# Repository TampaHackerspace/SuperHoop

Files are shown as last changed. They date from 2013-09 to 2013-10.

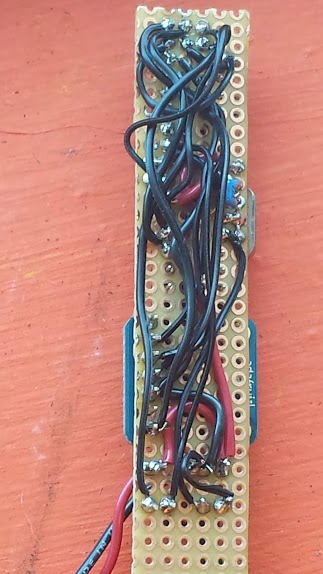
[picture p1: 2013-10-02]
code/SuperHoop_PCB/20131002_133408.jpg

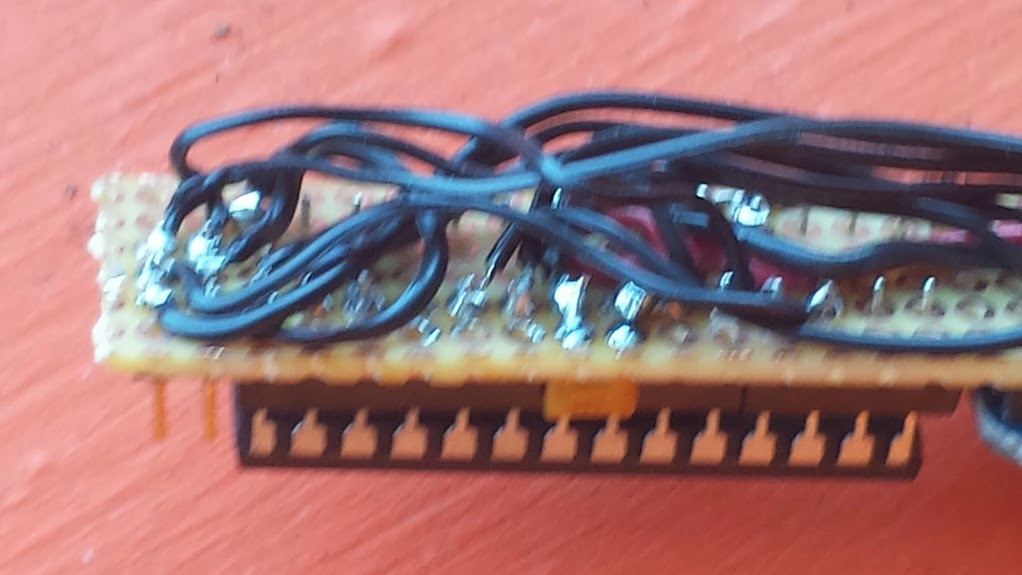
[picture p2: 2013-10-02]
code/SuperHoop_PCB/20131002_133213.jpg

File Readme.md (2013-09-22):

#Orlando Mini Maker Faire Project Planner
#Super Hoop

##Objective
Create a spectacle to attract attention and bring people into our exhibit so that our members can talk about their projects and we can promote our new Tampa Hackerspace. The project should be portable and kid friendly for future use.

##Project Idea
Embed addressable LEDs into clear hula hoops and instrument them with a programmable microcontroller and sensors so that we can make games and use them creatively.

##Sensors
accelerometer
photo electric cell and/or color sensor
grip sensor
proximity sensors

##Applications / Games
Persistence of Vision display. Spin the hoops rapidly to make colorful displays

How high can you go? Compete to see who can toss the hoop the highest and safely catch it.

Ring toss. Two or more players toss the hoops between themselves. Take a step back at each successful catch and keep going to see how long you can keep the game going.

Ultimate Ring Golf: Play it like ultimate frisbee but use the rings.

Horseshoes: Rings instead of horseshoes. Same rules.

Fasted hoop: First one to spin their hoop hula style 100 rotations wins.

Billboard: Use a wireless controller to stream dynamic text that displays while spinning?

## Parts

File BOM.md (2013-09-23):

- Atmega168 DIP IC
- 28 pin DIP IC socket
- Perfboard (4x6 phenolic or similar)
- Neopixel Addressable LEDs
- 3/4" Sharkbite Tubing (10ft stick per large hoop, 39 inch per small hoop)
- 1" Sharkbite tubing (holds batteries and Accelerometer)
- ADXL335 Accelerometer
- 16 MHz Crystal(1 per hoop)
- 22pF caps(2 per hoop)
- 10uF caps(2 per hoop)

##To buy:
- voltage boost circuit(3.7->5v)  NEED to order [one possible source: https://www.sparkfun.com/products/8290  ]
    we may be able to disable brown out fuse and run at 3.6v, but untested yet. need atmel programmer, Dan can't find his.
- Single AA battery holster (3 per large hoop, 2 per small hoop)  NEED to order [possible source: http://www.radioshack.com/product/index.jsp?productId=2062247  ]
- AA battery (3 per large hoop, 2 per small, Lithium 3.7v 2500ma or similar model 18650 with charger)  NEED to order
- VALCO Snap button (2 per hoop)  [mcmaster.com p/n 94282A250  http://www.mcmaster.com/#94282a250/=omgo4b   ]

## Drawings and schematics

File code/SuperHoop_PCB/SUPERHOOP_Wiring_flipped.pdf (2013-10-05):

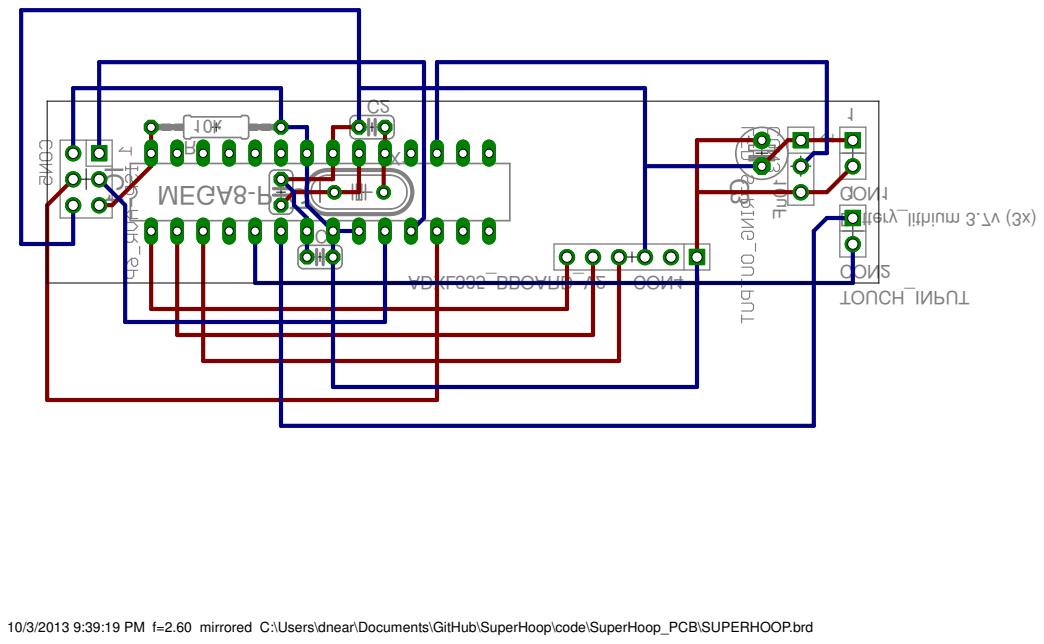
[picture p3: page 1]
MEGA8-P; Battery_lithium 3.7v (3x); ADXL335_BBOARD_V2; TOUCH_INPUT; C1CON1; CON4; CON2

10/3/2013 9:39:19 PM f=2.60 mirrored C:\Users\dnear\Documents\GitHub\SuperHoop\code\SuperHoop_PCB\SUPERHOOP.brd

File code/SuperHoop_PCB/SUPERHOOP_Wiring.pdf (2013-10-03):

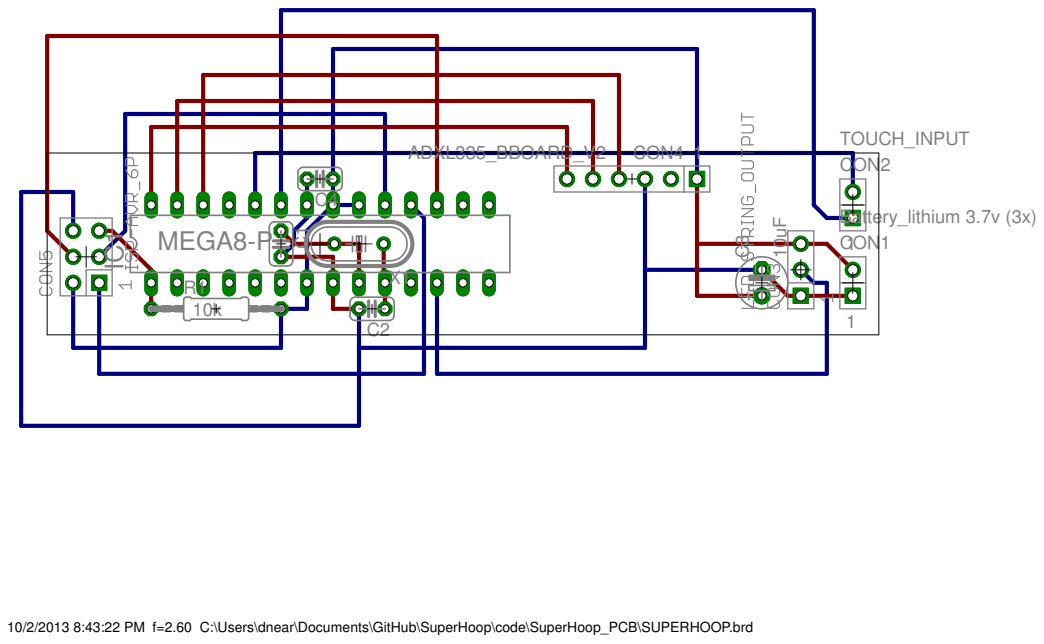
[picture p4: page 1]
C1 CON1; CON4; CON2; MEGA8-P; Battery_lithium 3.7v (3x); ADXL335_BBOARD_V2; TOUCH_INPUT

10/2/2013 8:43:22 PM f=2.60 C:\Users\dnear\Documents\GitHub\SuperHoop\code\SuperHoop_PCB\SUPERHOOP.brd

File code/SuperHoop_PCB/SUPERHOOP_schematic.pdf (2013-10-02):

A

A

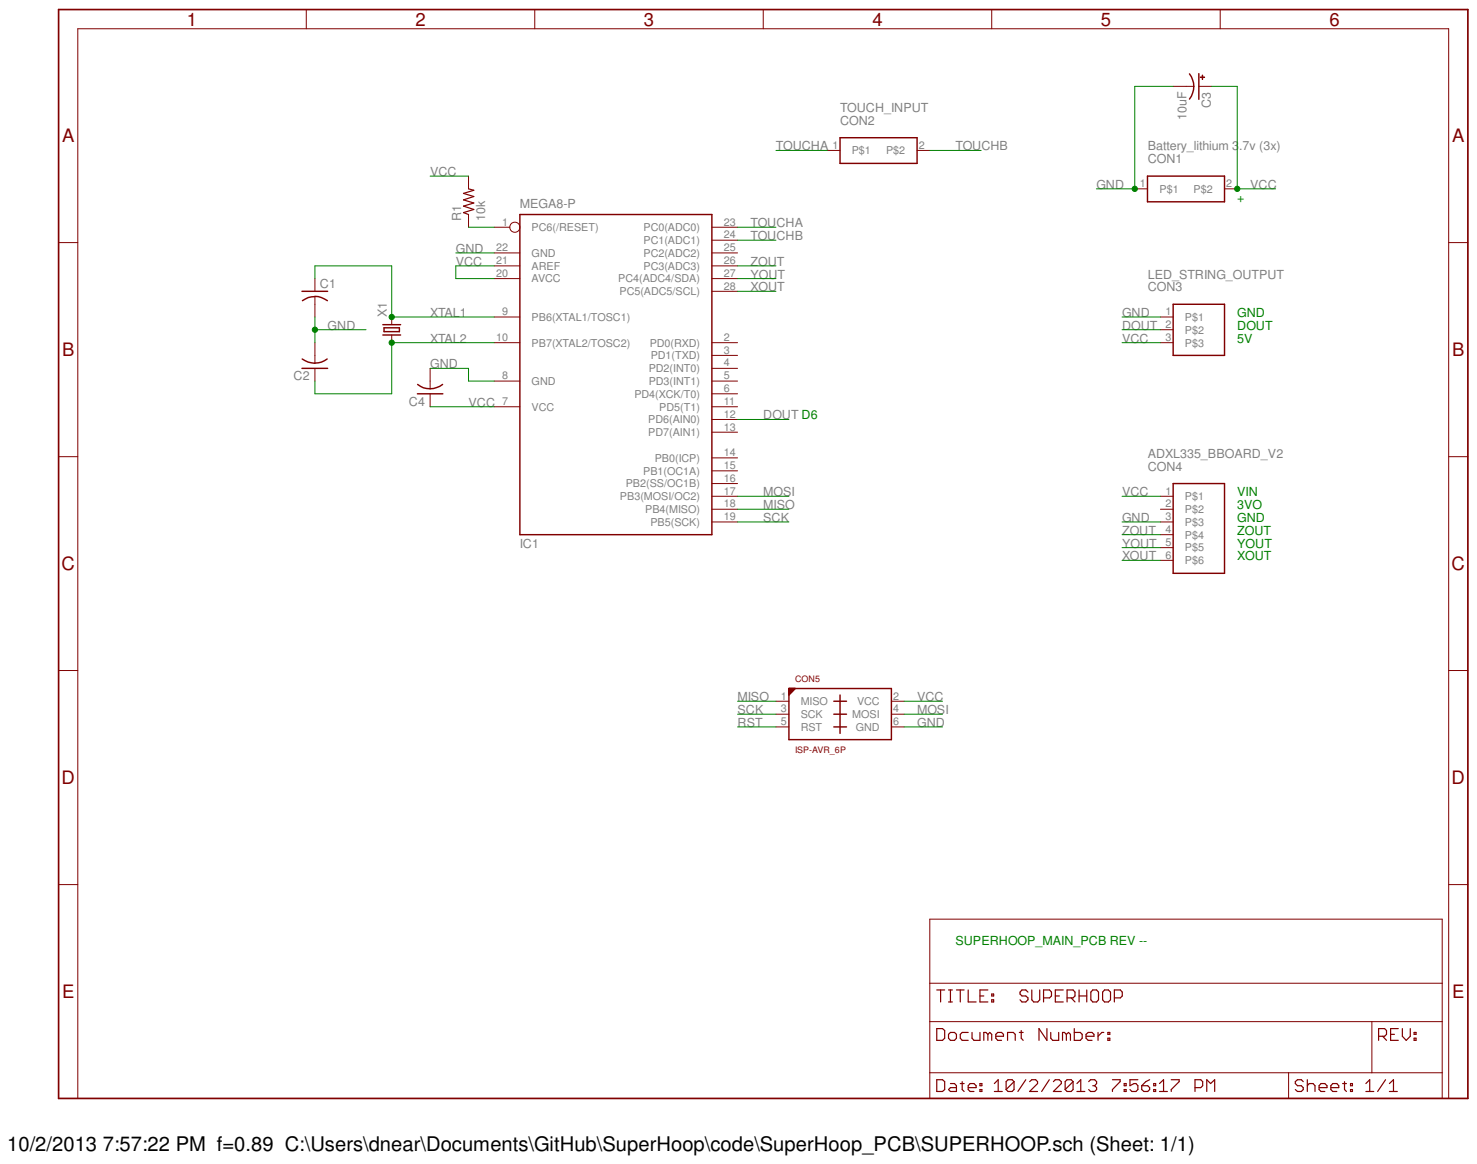
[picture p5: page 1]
Battery_lithium 3.7v (3x); LED_STRING_OUTPUT; ADXL335_BBOARD_V2; TOUCH_INPUT; PB5(SCK); PB7(XTAL2/TOSC2) 10; PB6(XTAL1/TOSC1) 9; GND 8; VCC 7; GND 22 AREF 21 AVCC 20; PB4(MISO); 18 PB3(MOSI/OC2); 15 PB0(ICP); PD7(AIN1); 13 PD6(AIN0); 11 PD4(XCK/T0); 6 PD3(INT1); 5 PD2(INT0); 4 PD1(TXD); 3 PD0(RXD); PC5(ADC5/SCL); 28 PC4(ADC4/SDA); 27 PC3(ADC3); 26 PC2(ADC2); 25 PC1(ADC1); 24 PC0(ADC0); 23 PC6(/RESET) 1; CON1; CON3; CON4; CON2; MISO 1 SCK 3; RST 5; GND; 6 MOSI; 4 VCC; VCC; DOUT; XTAL1; XTAL2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

MEGA8-P

10/2/2013 7:57:22 PM f=0.89 C:\Users\dnear\Documents\GitHub\SuperHoop\code\SuperHoop_PCB\SUPERHOOP.sch (Sheet: 1/1)

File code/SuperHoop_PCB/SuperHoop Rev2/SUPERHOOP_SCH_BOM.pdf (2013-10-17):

A

A

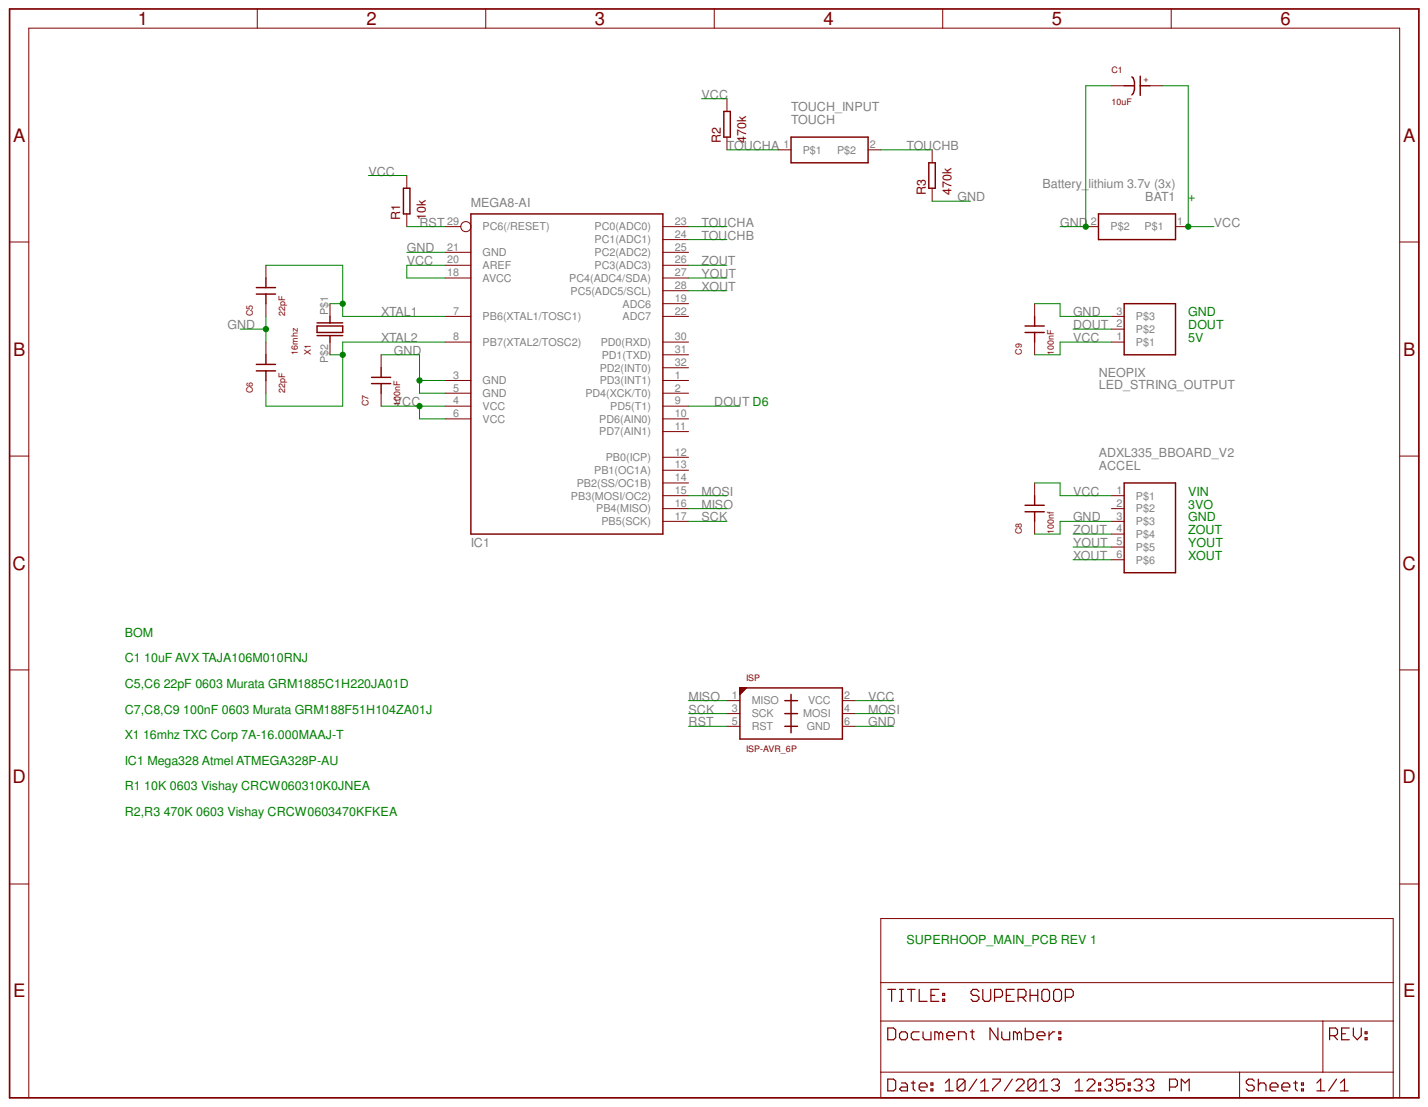
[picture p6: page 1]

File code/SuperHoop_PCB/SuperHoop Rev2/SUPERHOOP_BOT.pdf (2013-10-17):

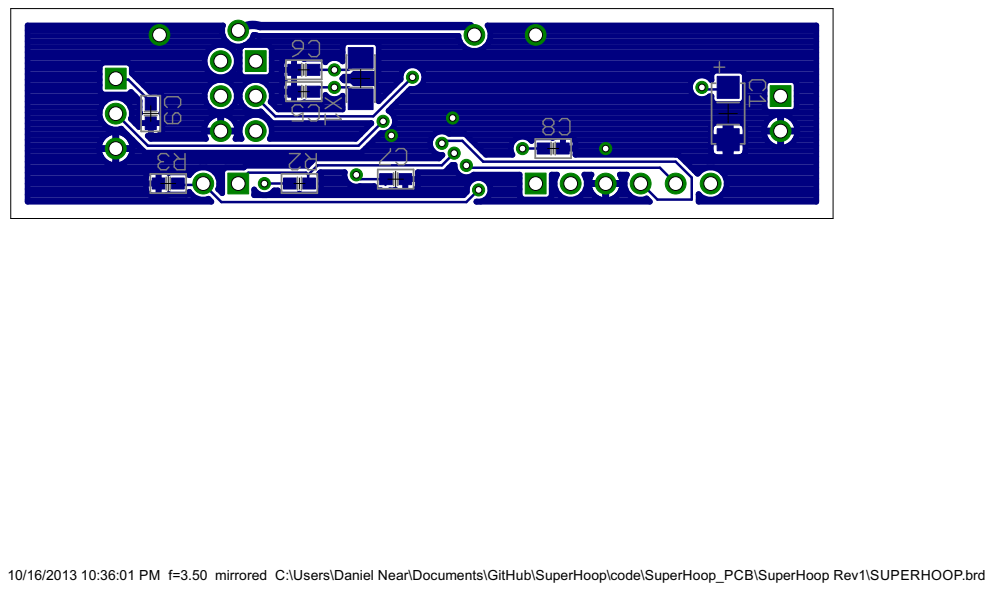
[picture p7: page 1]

10/16/2013 10:36:01 PM f=3.50 mirrored C:\Users\Daniel Near\Documents\GitHub\SuperHoop\code\SuperHoop_PCB\SuperHoop Rev1\SUPERHOOP.brd

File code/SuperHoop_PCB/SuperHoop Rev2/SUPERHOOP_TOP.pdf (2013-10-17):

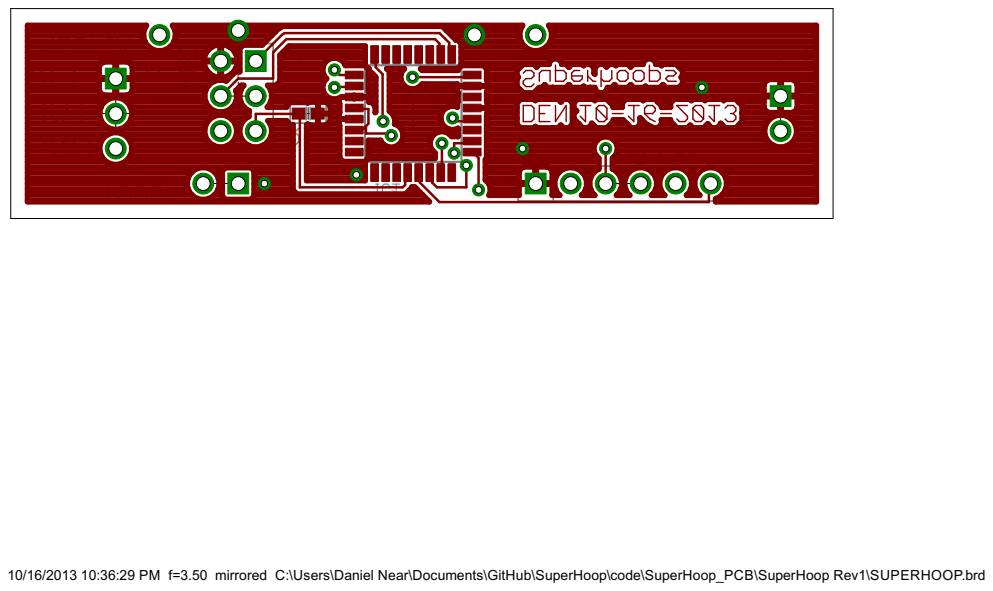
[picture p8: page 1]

10/16/2013 10:36:29 PM f=3.50 mirrored C:\Users\Daniel Near\Documents\GitHub\SuperHoop\code\SuperHoop_PCB\SuperHoop Rev1\SUPERHOOP.brd

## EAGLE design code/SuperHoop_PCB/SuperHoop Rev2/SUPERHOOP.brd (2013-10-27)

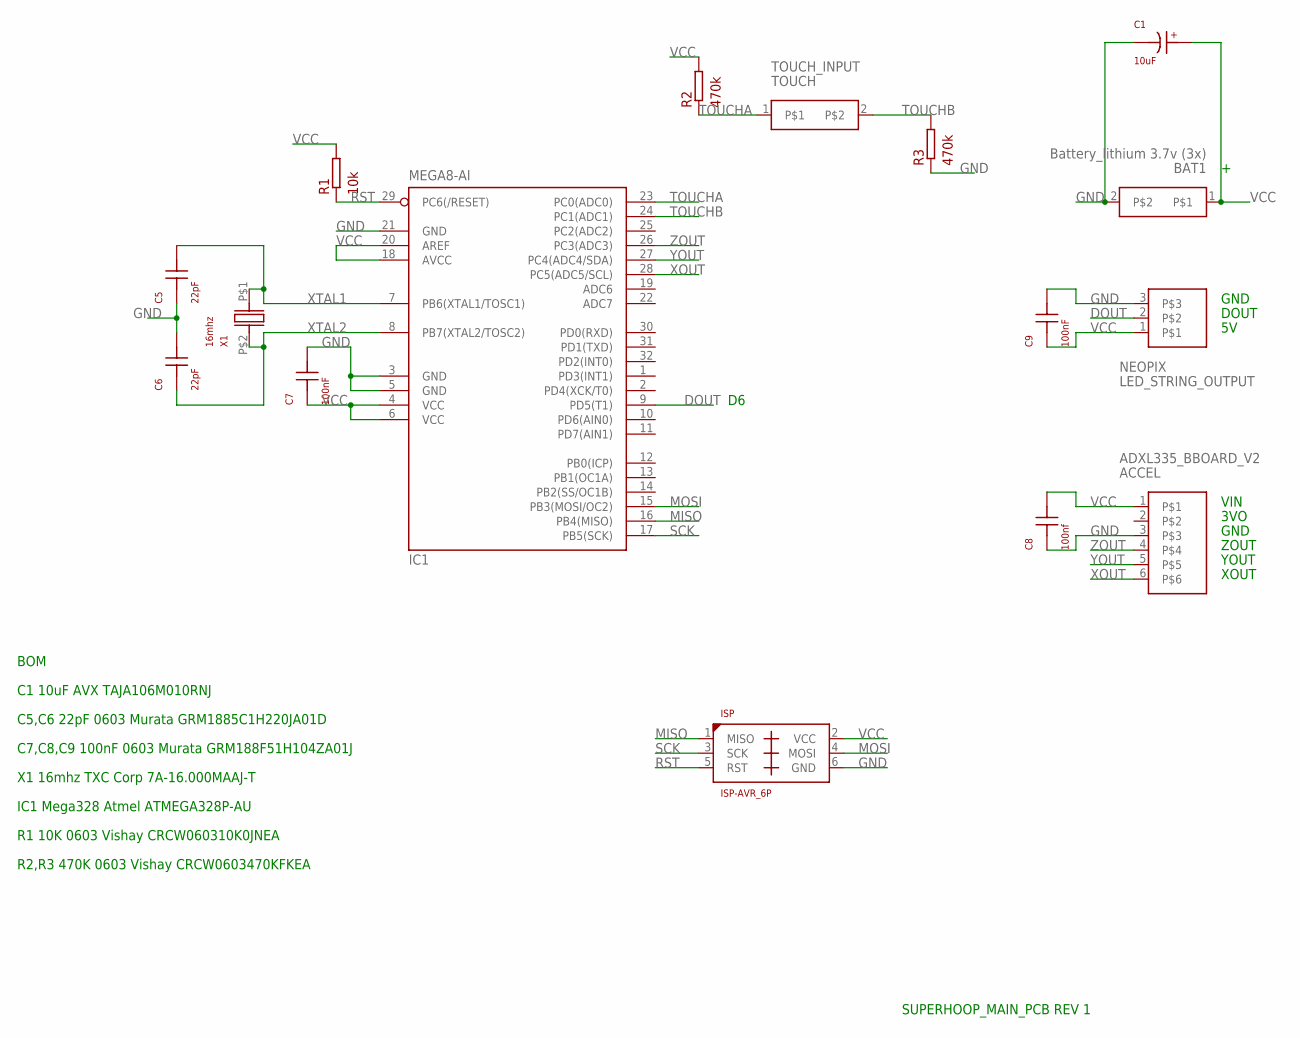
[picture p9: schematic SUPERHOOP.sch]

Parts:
ACCEL: ADXL335_BBOARD_V2; HEADER_6X1_2.54
BAT1: Battery_lithium 3.7v (3x); HEADER_2X1_2.54
C1: 10uF; CAP_POL_1206
C5, C6: 22pF; SMD_0603
C7, C9: 100nF; SMD_0603
C8: 100nf; SMD_0603
IC1: MEGA8-AI; TQFP32-08
ISP: ISP-AVR_6P; HEADER_3X2_2.54
NEOPIX: LED_STRING_OUTPUT; HEADER_3X1_2.54
R1: 10k; SMD_0603
R2, R3: 470k; SMD_0603
TOUCH: TOUCH_INPUT; HEADER_2X1_2.54
X1: 16mhz; CRYSTAL_5.0X3.2

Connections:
DOUT: IC1.9 (PD5(T1)), NEOPIX.2
GND: ACCEL.3, BAT1.2, C1.N, C5.P$1, C6.P$2, C7.P$2, C8.P$1, C9.P$2, IC1.3 (GND), IC1.5 (GND), IC1.21 (GND), ISP.6 (GND), NEOPIX.3, R3.P$1
MISO: IC1.16 (PB4(MISO)), ISP.1 (MISO)
MOSI: IC1.15 (PB3(MOSI/OC2)), ISP.4 (MOSI)
RST: IC1.29 (PC6(/RESET)), ISP.5 (RST), R1.P$1
SCK: IC1.17 (PB5(SCK)), ISP.3 (SCK)
TOUCHA: IC1.23 (PC0(ADC0)), R2.P$1, TOUCH.1
TOUCHB: IC1.24 (PC1(ADC1)), R3.P$2, TOUCH.2
VCC: ACCEL.1, BAT1.1, C1.P, C7.P$1, C8.P$2, C9.P$1, IC1.4 (VCC), IC1.6 (VCC), IC1.18 (AVCC), IC1.20 (AREF), ISP.2 (VCC), NEOPIX.1, R1.P$2, R2.P$2
XOUT: ACCEL.6, IC1.28 (PC5(ADC5/SCL))
XTAL1: C5.P$2, IC1.7 (PB6(XTAL1/TOSC1)), X1.P$1
XTAL2: C6.P$1, IC1.8 (PB7(XTAL2/TOSC2)), X1.P$2
YOUT: ACCEL.5, IC1.27 (PC4(ADC4/SDA))
ZOUT: ACCEL.4, IC1.26 (PC3(ADC3))

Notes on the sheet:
GND
DOUT
VIN
ZOUT
YOUT
XOUT
3VO
SUPERHOOP_MAIN_PCB REV 1
BOM
C5,C6 22pF 0603 Murata GRM1885C1H220JA01D
C1 10uF AVX TAJA106M010RNJ
C7,C8,C9 100nF 0603 Murata GRM188F51H104ZA01J
X1 16mhz TXC Corp 7A-16.000MAAJ-T
IC1 Mega328 Atmel ATMEGA328P-AU
R1 10K 0603 Vishay CRCW060310K0JNEA
R2,R3 470K 0603 Vishay CRCW0603470KFKEA

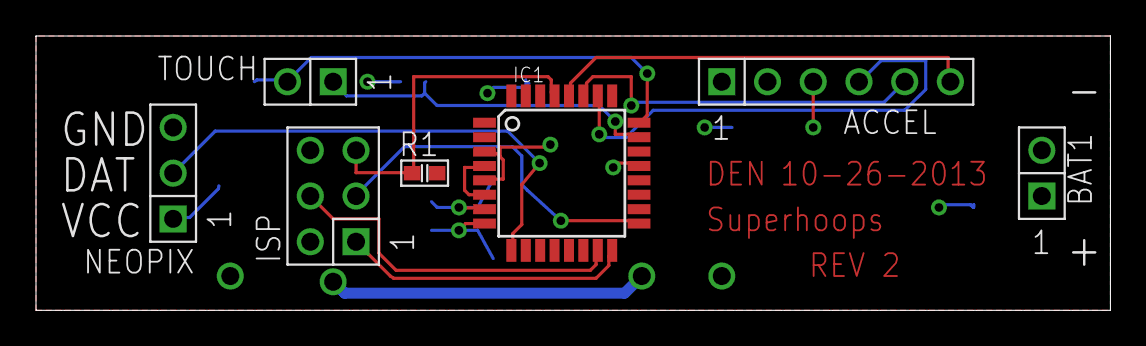
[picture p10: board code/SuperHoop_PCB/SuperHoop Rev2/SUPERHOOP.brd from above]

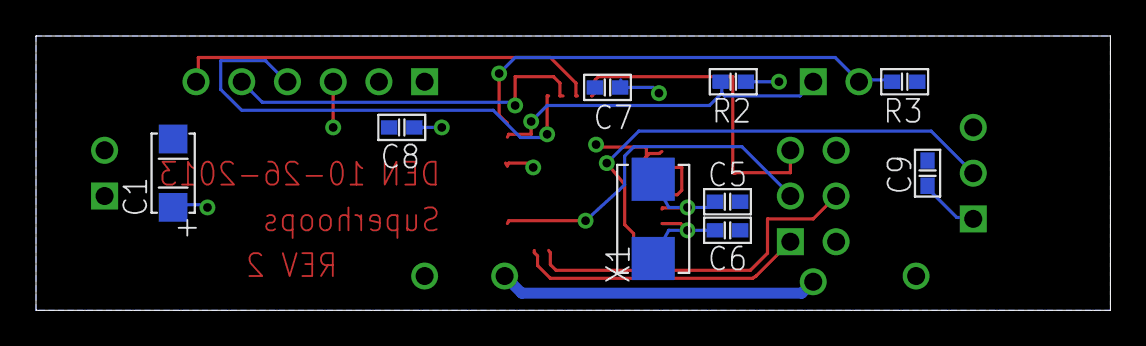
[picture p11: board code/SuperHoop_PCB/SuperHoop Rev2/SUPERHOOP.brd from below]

Board: 2 copper layers, 59.7 x 15.2 mm, 16 parts (9 on the bottom side), 14 nets.

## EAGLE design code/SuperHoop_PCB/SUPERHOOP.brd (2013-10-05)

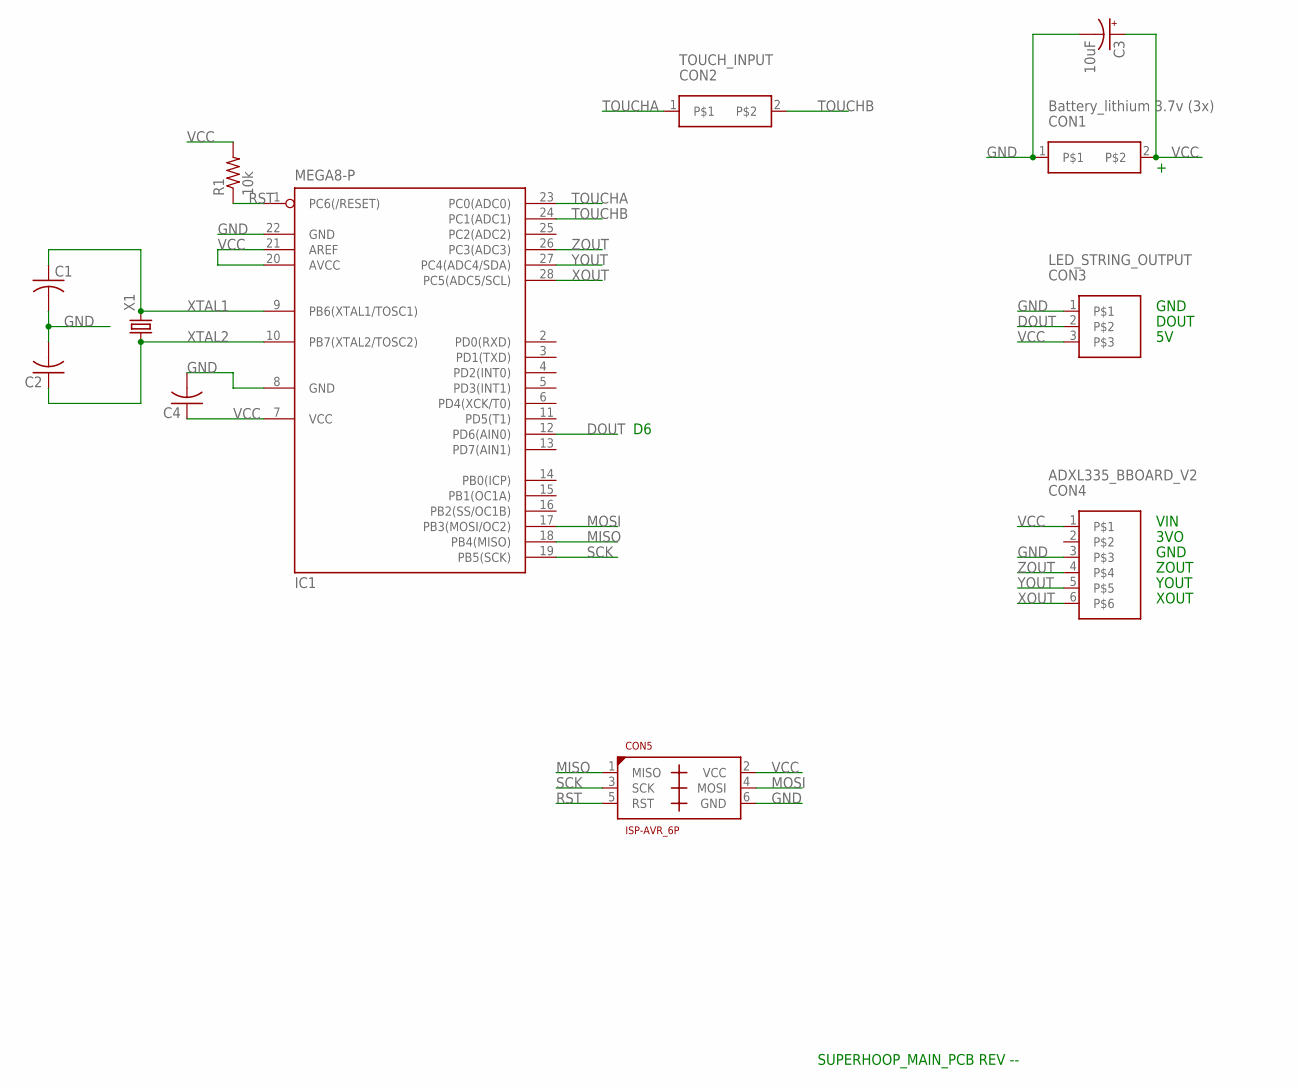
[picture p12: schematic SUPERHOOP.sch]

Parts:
C1, C2, C4: C-US025-024X044; C025-024X044
C3: 10uF; E2,5-5
CON1: Battery_lithium 3.7v (3x); HEADER_2X1_2.54
CON2: TOUCH_INPUT; HEADER_2X1_2.54
CON3: LED_STRING_OUTPUT; HEADER_3X1_2.54
CON4: ADXL335_BBOARD_V2; HEADER_6X1_2.54
CON5: ISP-AVR_6P; HEADER_3X2_2.54
IC1: MEGA8-P; DIL28-3
R1: 10k; 0207/12
X1: CRYSTALHC49S; HC49/S

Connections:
DOUT: CON3.2, IC1.12 (PD6(AIN0))
GND: C1.2, C2.2, C3.-, C4.2, CON1.1, CON3.1, CON4.3, CON5.6 (GND), IC1.8 (GND), IC1.22 (GND)
MISO: CON5.1 (MISO), IC1.18 (PB4(MISO))
MOSI: CON5.4 (MOSI), IC1.17 (PB3(MOSI/OC2))
RST: CON5.5 (RST), IC1.1 (PC6(/RESET)), R1.1
SCK: CON5.3 (SCK), IC1.19 (PB5(SCK))
TOUCHA: CON2.1, IC1.23 (PC0(ADC0))
TOUCHB: CON2.2, IC1.24 (PC1(ADC1))
VCC: C3.+, C4.1, CON1.2, CON3.3, CON4.1, CON5.2 (VCC), IC1.7 (VCC), IC1.20 (AVCC), IC1.21 (AREF), R1.2
XOUT: CON4.6, IC1.28 (PC5(ADC5/SCL))
XTAL1: C1.1, IC1.9 (PB6(XTAL1/TOSC1)), X1.2
XTAL2: C2.1, IC1.10 (PB7(XTAL2/TOSC2)), X1.1
YOUT: CON4.5, IC1.27 (PC4(ADC4/SDA))
ZOUT: CON4.4, IC1.26 (PC3(ADC3))

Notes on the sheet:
GND
DOUT
VIN
ZOUT
YOUT
XOUT
3VO
SUPERHOOP_MAIN_PCB REV --

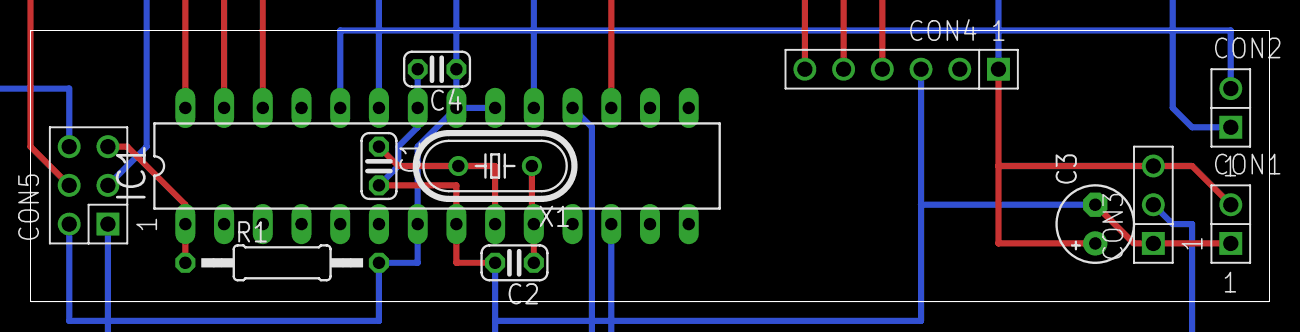
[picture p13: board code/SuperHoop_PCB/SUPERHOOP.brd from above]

Board: 2 copper layers, 81.3 x 17.8 mm, 12 parts (0 on the bottom side), 14 nets.

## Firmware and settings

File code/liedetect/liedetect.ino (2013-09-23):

int redPin = 9;
int greenPin = 10;
int bluePin = 11;
int buzzerPin = 7;
int potPin = 1;
int sensorPin = 0;
long red = 0xFF0000;
long green = 0x00FF00;
long blue = 0x000080;
int band = 6;
// adjust for sensitivity
void setup()
{
  pinMode(potPin, INPUT);
  pinMode(sensorPin, INPUT);
  pinMode(redPin, OUTPUT);
  pinMode(greenPin, OUTPUT);
  pinMode(bluePin, OUTPUT);
  pinMode(buzzerPin, OUTPUT);
}
void loop()
{
  int gsr = analogRead(sensorPin);
  int pot = analogRead(potPin);
  if (gsr > pot + band)
  {
    setColor(red);
    beep();
  }
  else if (gsr < pot - band)
  {
    setColor(blue);
  }
  else
  {
    setColor(green);
  }
}
void setColor(long rgb)
{
  int red = rgb >> 16;
  int green = (rgb >> 8) & 0xFF;
  int blue = rgb & 0xFF;
  analogWrite(redPin, 255 - red);
  analogWrite(greenPin, 255 - green);
  analogWrite(bluePin, 255 - blue);
}
void beep()
{
  // 5 Khz for 1/5th second
  for (int i = 0; i < 1000; i++)
  {
    digitalWrite(buzzerPin, HIGH);
    delayMicroseconds(100);
    digitalWrite(buzzerPin, LOW);
    delayMicroseconds(100);
  }
}

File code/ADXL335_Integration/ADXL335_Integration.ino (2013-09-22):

#include <Adafruit_NeoPixel.h>

//Code by Daniel Near
// 09-21-2013

#define PIN 6//digital out to neopixel strip
#define PIXELS 90
#define PATTERN_SIZE 18
#define DELAY 32
//r=0x1,0x2, g=0x4,0x8, b=0x10,0x20
byte aztekpattern[12][18]={//array image to display, 18 pixels with 12 scan lines
  {  
    0x00,0x00,0x00,0x00,0x00,0x00,0x00,0x00,0x00,0x00,0x00,0x00,0x10,0x11,0x11,0x12,0x13,0x13  }
  ,
  {  
    0x00,0x04,0x04,0x04,0x04,0x04,0x00,0x00,0x00,0x00,0x00,0x10,0x00,0x00,0x00,0x00,0x00,0x13  }
  ,
  {  
    0x00,0x04,0x00,0x00,0x00,0x04,0x00,0x00,0x00,0x00,0x20,0x00,0x00,0x21,0x21,0x22,0x00,0x23  }
  ,
  {  
    0x00,0x08,0x00,0x08,0x00,0x08,0x00,0x00,0x00,0x24,0x00,0x00,0x00,0x31,0x00,0x32,0x00,0x33  }
  ,
  {  
    0x00,0x08,0x00,0x08,0x08,0x08,0x00,0x00,0x34,0x00,0x00,0x00,0x00,0x33,0x00,0x00,0x00,0x33  }
  ,
  {  
    0x00,0x0C,0x00,0x00,0x00,0x00,0x00,0x38,0x00,0x00,0x00,0x00,0x00,0x33,0x33,0x33,0x33,0x33  }
  ,
  {  
    0x00,0x0C,0x0C,0x0C,0x0C,0x0C,0x09,0x00,0x00,0x00,0x00,0x00,0x00,0x00,0x00,0x00,0x00,0x00  }
  ,
  {  
    0x00,0x0C,0x00,0x00,0x00,0x00,0x00,0x0d,0x00,0x00,0x00,0x00,0x00,0x33,0x33,0x33,0x33,0x33  }
  ,
  {  
    0x00,0x08,0x00,0x08,0x08,0x08,0x00,0x00,0x0e,0x00,0x00,0x00,0x00,0x33,0x00,0x00,0x00,0x33  }
  ,
  {  
    0x00,0x08,0x00,0x08,0x00,0x08,0x00,0x00,0x00,0x02,0x00,0x00,0x00,0x31,0x00,0x32,0x00,0x33  }
  ,
  {  
    0x00,0x04,0x00,0x00,0x00,0x04,0x00,0x00,0x00,0x00,0x03,0x00,0x00,0x21,0x21,0x22,0x00,0x23  }
  ,
  {  
    0x00,0x04,0x04,0x04,0x04,0x04,0x00,0x00,0x00,0x00,0x00,0x03,0x00,0x00,0x00,0x00,0x00,0x13  }
};

// Parameter 1 = number of pixels in strip
// Parameter 2 = pin number (most are valid)
// Parameter 3 = pixel type flags, add together as needed:
//   NEO_KHZ800  800 KHz bitstream (most NeoPixel products w/WS2812 LEDs)
//   NEO_KHZ400  400 KHz (classic 'v1' (not v2) FLORA pixels, WS2811 drivers)
//   NEO_GRB     Pixels are wired for GRB bitstream (most NeoPixel products)
//   NEO_RGB     Pixels are wired for RGB bitstream (v1 FLORA pixels, not v2)
Adafruit_NeoPixel strip = Adafruit_NeoPixel(90, PIN, NEO_GRB + NEO_KHZ800);
int zPin = 3;
int yPin = 4;
int xPin = 5;

int frame = 0;
int yVal = 0;


void setup() {
  pinMode(A0, OUTPUT);
  digitalWrite(A0, HIGH);
  pinMode(A2, OUTPUT);
  digitalWrite(A2, LOW);
  strip.begin();
  strip.show(); // Initialize all pixels to 'off'
  Serial.begin(9600);
}

void loop() {
  yVal = analogRead(yPin);
  Serial.println(abs((yVal-300)/8)%12);
  render_frame(abs((yVal-300)/8)%12);
  frame++;
  frame = frame%12;
  delay(DELAY);
}
void render_frame(int frame)
{
    for(int16_t i=0;i<PATTERN_SIZE;i++)
    {

      for(int16_t offset=0; offset < PIXELS; offset+=PATTERN_SIZE){
        strip.setPixelColor(i+offset,replaceColor(aztekpattern[frame][i]));
      }
    }
    strip.show(); // push out to strip
 
}
unsigned long replaceColor(byte color)//extend 2 bits to 24 and shift bits for brighter shades

{
  byte redcolor=((color & 0x02)<<6)|((color&0x01)<<5);
  byte grncolor=((color & 0x08)<<4)|((color&0x04)<<3);
  byte blucolor=((color & 0x30)<<2)|((color&0x04)<<1);//<<1;
  return strip.Color(redcolor,  grncolor,  blucolor);

}
// Fill the dots one after the other with a color

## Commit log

2013-09-22 Add comments to the replaceColor function
    [SuperHoopStrandtest.ino]
2013-09-22 Added SuperHoopStrandtet folder so arduino env doesnt whine
2013-09-22 Added in accelerometer integration test so that the frame it is rendering is dependent on the angle
2013-09-22 Changed drawpixels to render_frame to allow rendering arbitrary frames out of order
2013-09-22 updating replaceColor routine to switch case so I can fully light an LED wit 8 bit value
    [SuperHoopStrandtest.ino]
2013-09-22 Fixed some missing curly braces
    [SuperHoopStrandtest.ino]
2013-09-22 Lie detector code for arduino
2013-09-28 Updated to multi-pattern output
    Sum ting wong, the repeat pattern appears to crash the Arduino
    [SuperHoopStrandtest.ino]
2013-09-28 Working without pointers
    Working version that doesn't use pointers. cycles through our 9 current
    patterns every 20-ish seconds
    [SuperHoopStrandtest.ino]
2013-09-28 reversed some whites
    more visible, less overpowering with less white backgrounds
    [SuperHoopStrandtest.ino]
2013-09-29 Added Eagle Schematic
    [SUPERHOOP.sch]
2013-09-29 PCB layout complete
    [SUPERHOOP.brd]
2013-09-30 final changes from Sunday
    Saved Eagle files, shortened delay between pattern cycles to ~5 seconds
    [SUPERHOOP.brd, SUPERHOOP.sch]
2013-10-02 created PDF of schematic
2013-10-02 circuit board closeup pics for troubleshooting
2013-10-02 Fixed wrong wiring
    made the board wiring more readable
    [SUPERHOOP.brd, SUPERHOOP.sch]
2013-10-03 Fixed some wiring glitches
    missing reset pin and removed layer covering wires under crystal
2013-10-05 Converted patterns to const
    [SUPERHOOP.brd, SUPERHOOP.sch]
2013-10-17 pcb for production
    moved to SMD comps and laid out for production
    [SUPERHOOP.brd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]
2013-10-17 Revised BOM
    Added 2 layer prints and added BOM to schematic
2013-10-17 flipped right side up
    Schematic printer backwards, corrected this so it's readable.
2013-10-27 Gerbers as sent to Oshpark
    [SUPERHOOP.GKO]
2013-10-27 Fixed crystal footprint
    rev1 had 3.2x1.5, should have been 5.0x3.2 to fit specified part
    [SUPERHOOP.GBL, SUPERHOOP.GBO, SUPERHOOP.GBS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]
